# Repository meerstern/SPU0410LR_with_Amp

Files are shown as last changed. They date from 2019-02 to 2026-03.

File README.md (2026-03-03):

# SPU0410LR_with_Amp
The Converter board of Kicad Data for SPU0410LR with Apmlifer

## 概要
約50倍の増幅回路[TLV316][0]とKnowles社製[アナログ出力MEMSマイクSPU0410LR5H][1]を搭載した2.54mmピッチ変換基板です。  
可聴音から超音波(100Hz～80kHz)までの幅広い帯域を高感度にセンシングすることが可能です。  
超音波センサや超音波通信などに使用可能です。  
約50倍のアンプ回路を搭載することでArduinoといったマイコンのアナログ入力に直接接続できます。  
マイク穴は基板裏面の丸印部分です。  
電源電圧1.8V~3.6V

## 超音波マイク比較
 用途に応じて様々な製品をラインアップしています  
| 製品名 | インタフェース | アンプ搭載有無 | 用途 | 
|:---|:---|:---|:---|
| [アナログ出力マイク][A] | アナログ | 無 | 任意のアンプ回路を使用したい場合 | 
| [可変アンプ内蔵アナログ出力マイク][B] | アナログ | 有(可変1~50倍) | 増幅率の調整が必要な場合 |	
| [アンプ内蔵アナログ出力マイク(本製品)][C] |	アナログ | 有(固定50倍) | 一定した増幅が必要な場合	| 
| [デジタル出力マイク][D] |	デジタルPDM | 不要 | フルデジタルで実装する場合やワイドレンジが必要な場合 | 

## 販売サイト
  * [スイッチサイエンス][2]

## 告知
SPU0410LR5Hの生産完了に伴い、[後継品のSPV0142LR5H][5]に移行しました(26年4月)。

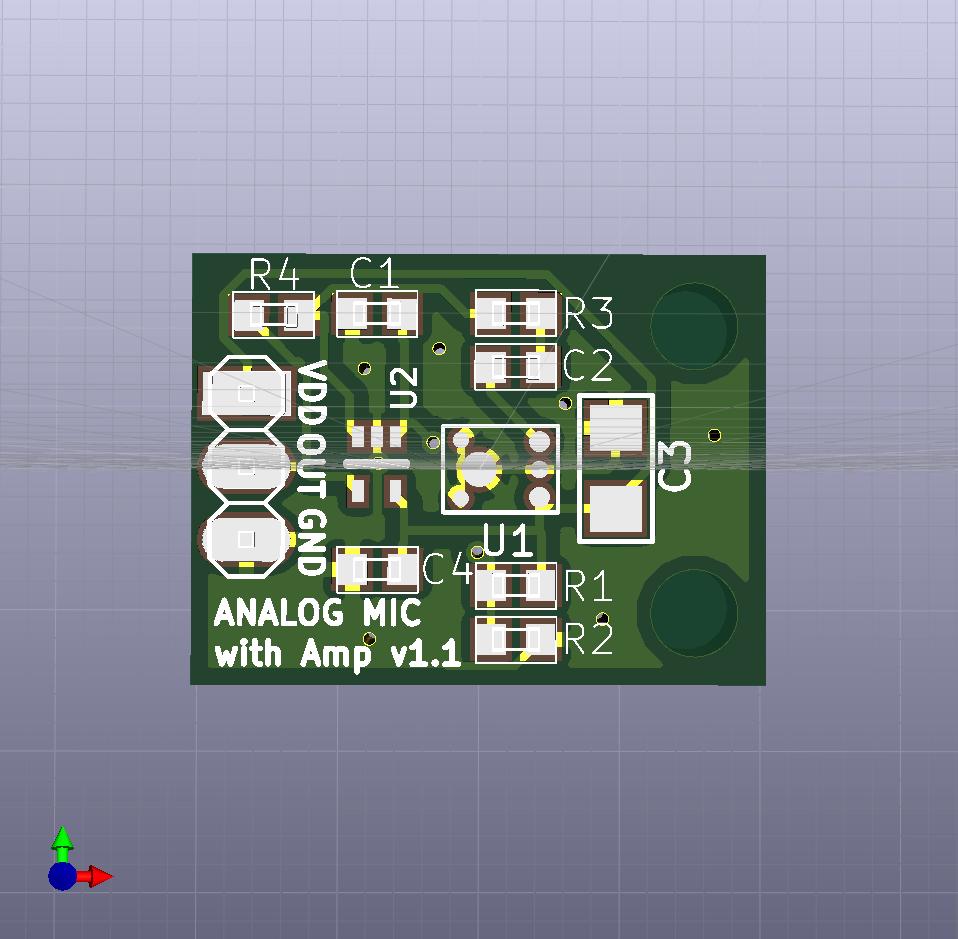
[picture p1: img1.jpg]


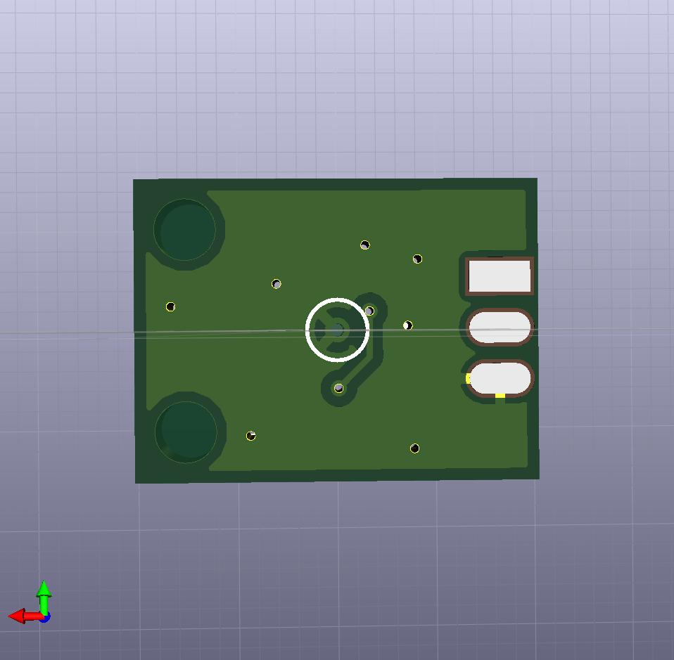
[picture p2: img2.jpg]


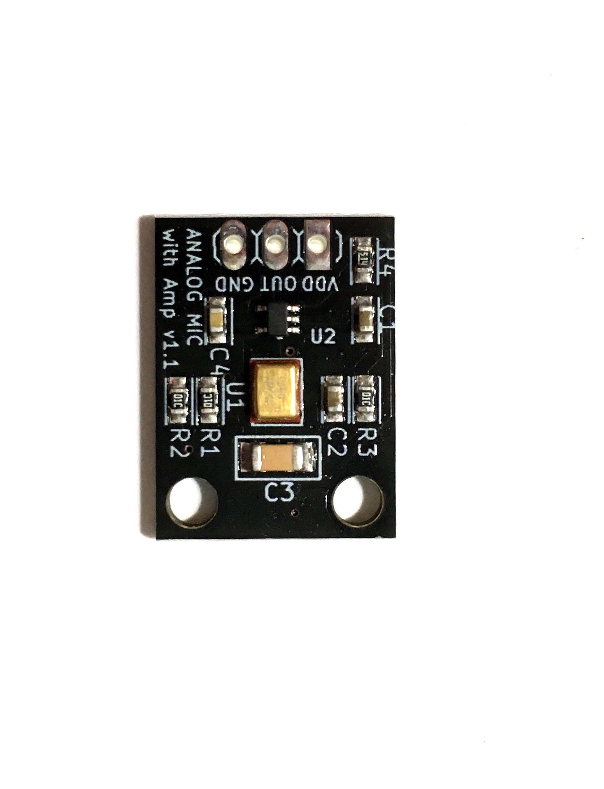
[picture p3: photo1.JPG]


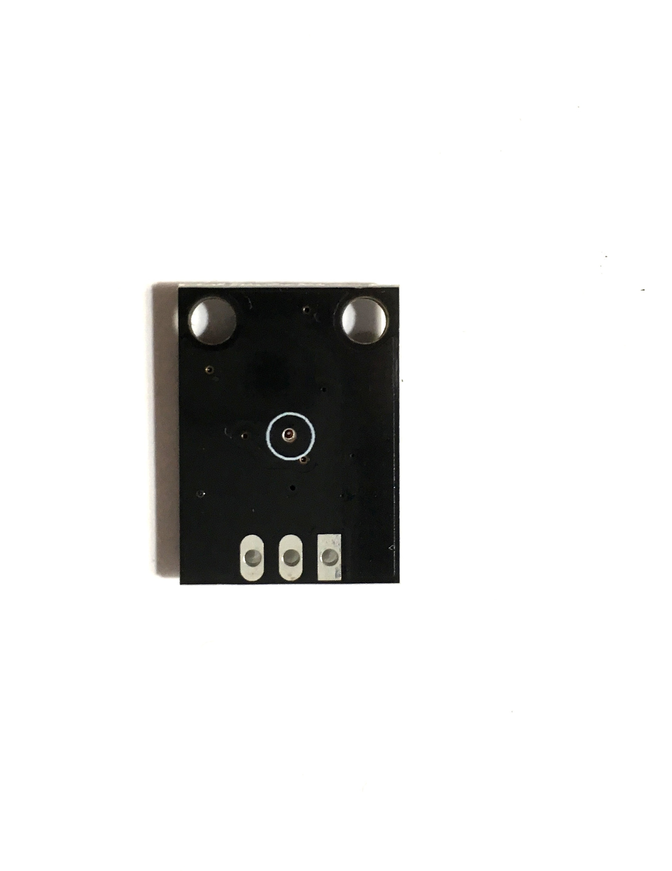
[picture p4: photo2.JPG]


License - MIT

[1]: https://www.digikey.jp/product-detail/ja/knowles/SPU0410LR5H-QB-7/423-1139-1-ND/2420983 "*1"
[0]: http://www.tij.co.jp/product/jp/TLV316 "*0"
[2]: https://www.switch-science.com/products/5462

[A]: https://github.com/meerstern/SPU0410LR
[B]: https://github.com/meerstern/SPU0410LR_with_VariableAmp
[C]: https://github.com/meerstern/SPU0410LR_with_Amp
[D]: https://github.com/meerstern/SPH0641LU
[5]: https://github.com/meerstern/SPV0142LR5H_with_Amp

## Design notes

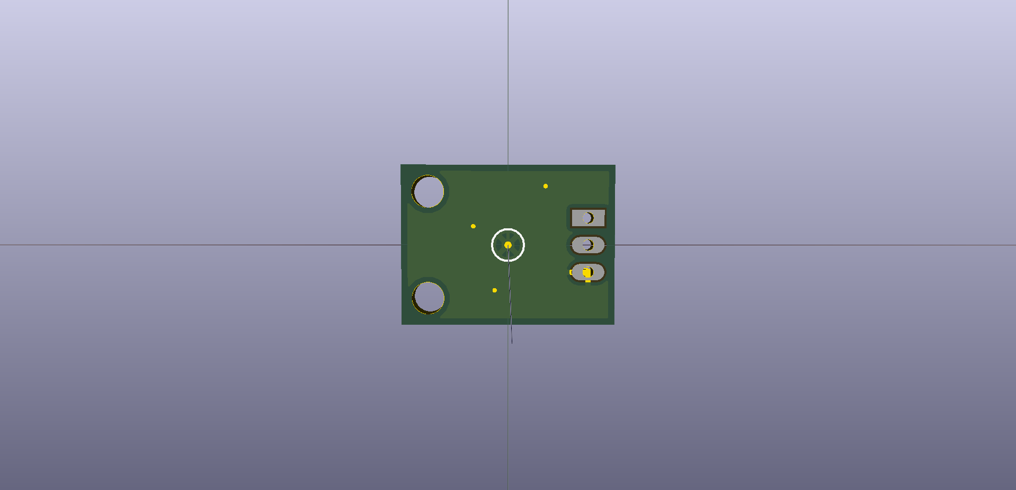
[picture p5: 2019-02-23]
SPU0410LR5H2.png

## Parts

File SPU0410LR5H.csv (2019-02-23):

ID | 参照記号 | パッケージ | 数 | 名称 | Supplier and ref
1 | REF2,REF1 | MountingHole_3mm | 2 | MountingHole_3mm
2 | P1 | pinhead-1X03 | 1 | Conn_01x03
3 | U1 | SPU0410LR5H | 1 | SPU0410LR5H
4 | C2,C1 | generic-SMD1608 | 2 | 4.7u
5 | C3 | C-1206 | 1 | 0.1u
6 | C4 | generic-SMD1608 | 1 | 0.1u
7 | R1,R2,R3 | generic-SMD1608 | 3 | 10k
8 | R4 | generic-SMD1608 | 1 | 500k
9 | U2 | SC-70-5 | 1 | LM321

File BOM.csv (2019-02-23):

Elecrow PN | Parts | Value | Package | QTY | Digikey/Mouser/Manufacturer Part | Remark/ Link
 | U1 | SPU0410LR5H | SPU0410LR5H | 1 | 423-1139-1-ND | https://www.digikey.jp/product-detail/ja/knowles/SPU0410LR5H-QB-7/423-1139-1-ND/2420983
C19666 | C2,C1 | 4.7u | SMD0603 | 2
 | C3 | 0.1u | SMD1206 | 1 | 490-1767-1-ND | https://www.digikey.jp/product-detail/ja/murata-electronics-north-america/GRM31C5C1E104JA01L/490-1767-1-ND/587366
C14663 | C4 | 0.1u | SMD0603 | 1
C25804 | R1,R2,R3 | 10k | SMD0603 | 3
C23192 | R4 | 510k | SMD0603 | 1
 | U2 | TLV316 | SC-70-5 | 1 | 296-47313-1-ND | https://www.digikey.jp/product-detail/ja/texas-instruments/TLV316IDCKR/296-47313-1-ND/7688323

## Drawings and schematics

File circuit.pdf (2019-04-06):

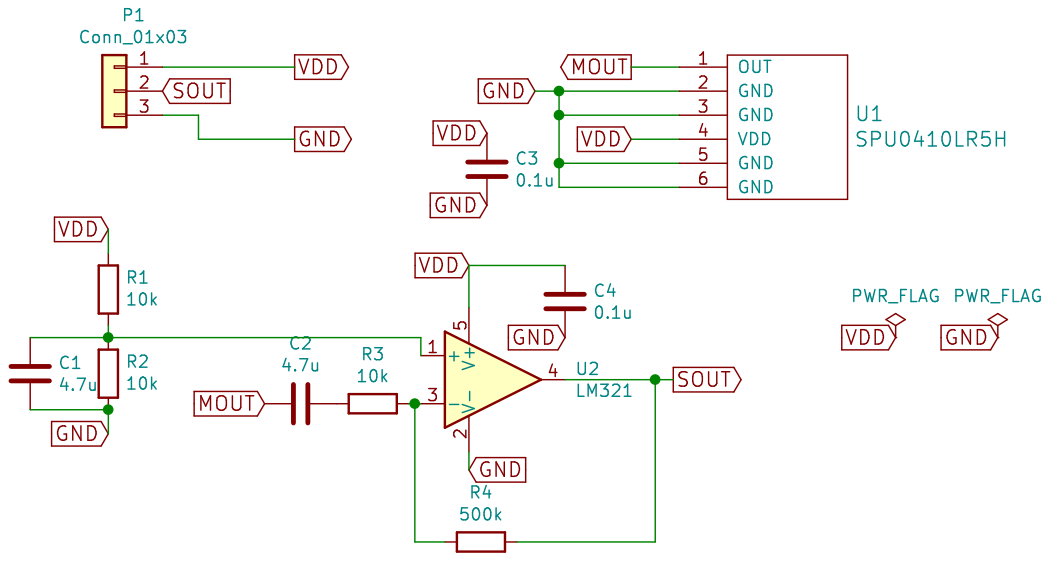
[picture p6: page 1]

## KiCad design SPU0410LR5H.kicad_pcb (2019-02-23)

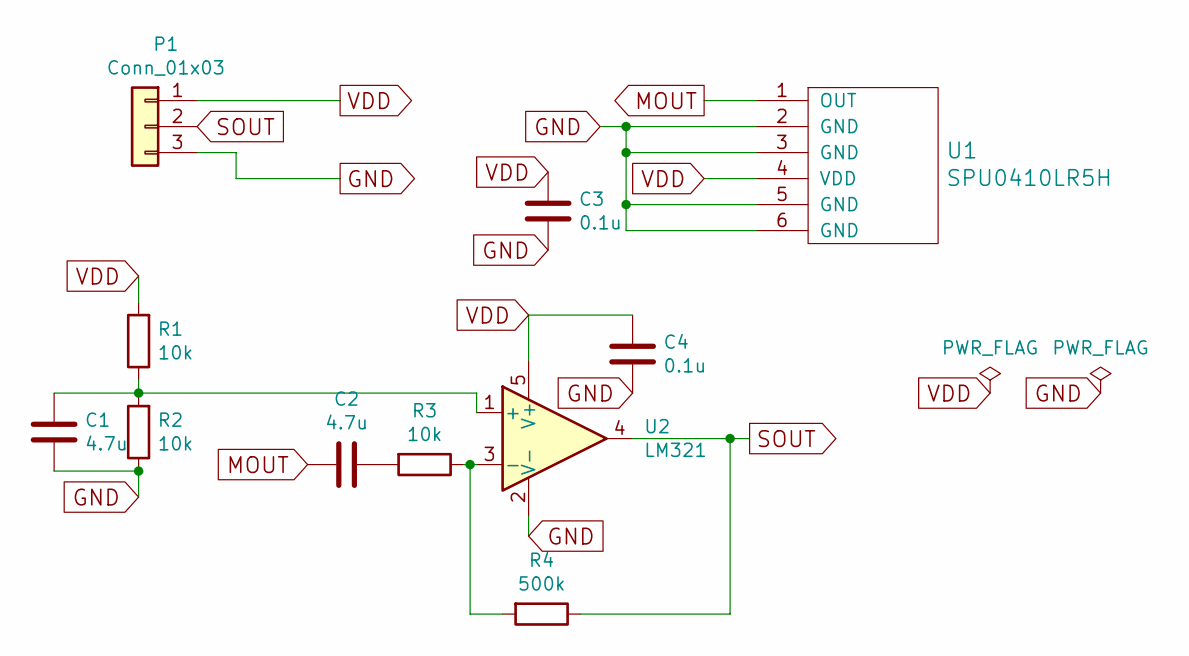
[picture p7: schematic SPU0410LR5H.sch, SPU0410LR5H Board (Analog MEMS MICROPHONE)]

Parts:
C1, C2: 4.7u; generic-SMD1608
C3: 0.1u; C-1206
C4: 0.1u; generic-SMD1608
P1: Conn_01x03; pinhead-1X03
R1, R2, R3: 10k; generic-SMD1608
R4: 500k; generic-SMD1608
U1: SPU0410LR5H
U2: LM321; SC-70-5

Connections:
GND: C1.2, C3.2, C4.2, P1.3, R2.1, U1.2 (GND), U1.3 (GND), U1.5 (GND), U1.6 (GND), U2.2 (V-)
MOUT: C2.2, U1.1 (OUT)
unnamed: C1.1, R1.1, R2.2, U2.1 (+)
unnamed: C2.1, R3.2
unnamed: R3.1, R4.2, U2.3 (-)
SOUT: P1.2, R4.1, U2.4
VDD: C3.1, C4.1, P1.1, R1.2, U1.4 (VDD), U2.5 (V+)

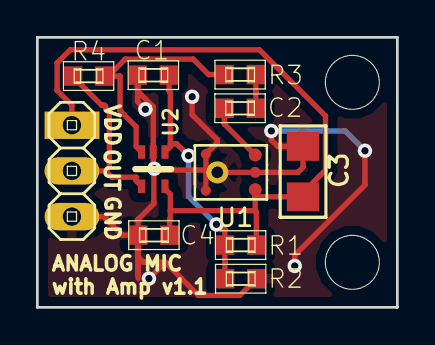
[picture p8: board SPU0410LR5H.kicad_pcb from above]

Board: 2 copper layers, 20.0 x 15.0 mm, 13 parts (0 on the bottom side), 7 nets.

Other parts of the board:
REF1, REF2: MountingHole_3mm
